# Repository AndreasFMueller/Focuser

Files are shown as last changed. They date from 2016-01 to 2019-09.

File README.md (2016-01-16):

# Focuser

The motor focus driver from starizona is quite feature complete,
more so than many other devices, but it is very large and heavy.
Also it is not possible to actuate the focuser without grabbing
the device, a wireless solution would be preferable. The present
project solves this problem.

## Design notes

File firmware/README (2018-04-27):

README for the focuser firmware project
---------------------------------------

Since the firmware reads the serial number from eeprom, it is necessary
to write the eeprom after flashing the device. The "make flash" command
is supposed to do that. But the serial number will then be 0000000. Use
the "serial" command of the fclient programm to set the serial number.

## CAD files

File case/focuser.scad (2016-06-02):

/*
 * focuser.stl -- case for the focuser 
 *
 * (c) 2016 Prof Dr Andreas Mueller, Hochschule Rapperswil
 */

board_width = 60.96 + 2 * 0.2;
board_height = 41.28 + 2 * 0.2;

w = board_width + 2 * 8;
h = board_height;
thickness = 1.5;
d = 10;

wall = 2;
W = w + 2 * wall;
H = h + 2 * wall;
D = d + 2 * wall;

dl = wall + 2 + thickness;
du = wall + d + 2;

module screwhole() {
    cylinder(r = 1.2, h = 20, center = true);
}

module bottom() {
	difference() {
		translate([0, 0, dl/2]) cube([W, H, dl], center = true);
		union() {
			translate([0, 0, wall + 2 + 1.5])
				cube([board_width, board_height, 3], center = true);
            translate([0, 0, wall + 5])
				cube([board_width - 1, board_height - 1, 10], center = true);
            // screw holes
            translate([board_width/2 + 6, 0, 0])
                screwhole();
            translate([-board_width/2 - 6, board_height/2 - 2, 0])
                screwhole();
            translate([-board_width/2 - 6, -board_height/2 + 2, 0])
                screwhole();
//            translate([0, 0, 5 + wall + 2 + 1.5 - 1])
//            difference() {
//                cube([W + 2, H + 2, 10], center = true);
//                cube([W - wall, H - wall, 12], center = true);
//            }
		}
	}
}

module screw() {
    union() {
        cylinder(r = 1.7, h = 30, center = true, $fn = 20);
        translate([0, 0, d-1])
            cylinder(r1 = 0, r2 = 3, h = 3, $fn = 20);
        translate([0, 0, d+2])
            cylinder(r = 3, h = 10, $fn = 20);
    }
}

module top() {
    difference() {
        union() {
            difference() {
                translate([0, 0, du / 2]) cube([W, H, du], center = true);
                union() {
                    translate([-3, 0, d/2 + 1])
                        cube([w - 6, h, d + 2], center = true);
                    // USB connector
                    translate([w / 2, 10.5, 10 - d + 2])
                        cube([20, 14, 20], center = true);
                    // motor cable opening
                    translate([w/2, -10, du/2 -d + 2.5])
                        cube([20, 5, 6], center = true);
                    // motor connector
                    //translate([w / 2, -10, du/2 - d + 2])
                    //    cube([20, 12, du], center = true);
                    // power cable opening
                    translate([w / 2 - 2, 12 + 4, 3.5 - d])
                        cube([10, 10, 20], center = true);
                }
            }
            translate([-board_width/2 - 6, board_height/2 - 2, du/2])
                cube([7, 7, du], center = true);
            translate([-board_width/2 - 6, -board_height/2 + 2, du/2])
                cube([7, 7, du], center = true);
            // board clamps bottom
            translate([0, -board_height/2, du/2])
                cube([4, 2, du], center = true);
            // board clamps top
            translate([board_width / 3, board_height/2, du/2])
                cube([4, 2, du], center = true);
            translate([-board_width / 3, board_height/2, du/2])
                cube([4, 2, du], center = true);
        }
        union() {
            // screw holes
            translate([board_width/2 + 6, 0, 0]) screw();
            translate([-board_width/2 - 6, board_height/2 - 2, 0]) screw();
            translate([-board_width/2 - 6, -board_height/2 + 2, 0]) screw();
            // LED holes
            translate([6, -16, 0])
                cylinder(r = 2.0, h = 30, center = true, $fn = 20);
            translate([27, -2, 0])
                cylinder(r = 2.0, h = 30, center = true, $fn = 20);
            translate([-11.5, 10.5, 0])
                cylinder(r = 2.0, h = 30, center = true, $fn = 20);
        }
    }
}

translate([0, 50, d + 4]) rotate([180, 0, 0]) top();
bottom();

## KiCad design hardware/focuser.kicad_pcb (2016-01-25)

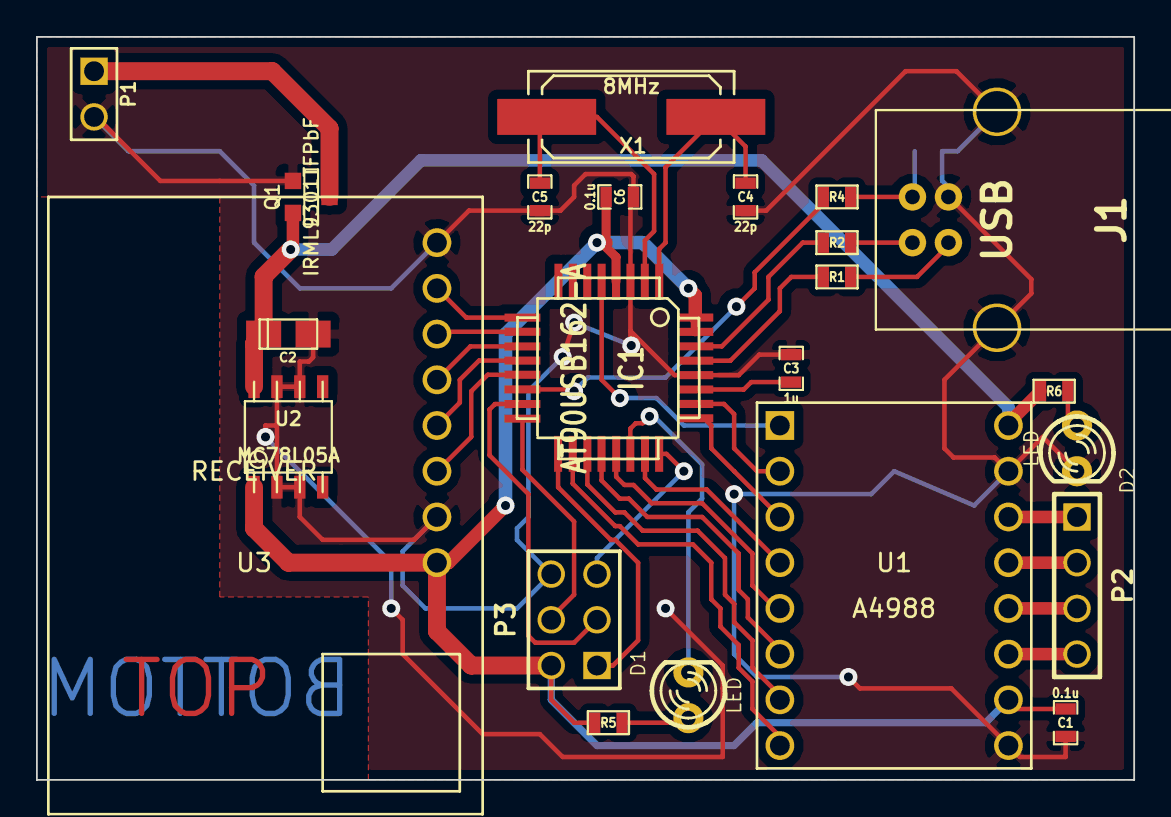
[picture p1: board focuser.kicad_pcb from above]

Board: 2 copper layers, 61.0 x 41.3 mm, 24 parts (1 on the bottom side), 37 nets.

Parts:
C1, C6: 0.1u; SM0603_Capa
C2: 0.33u; c_tant_A
C3: 1u; SM0603_Capa
C4, C5: 22p; SM0603_Capa
D1, D2: LED; LED-3MM
IC1: AT90USB162-A; TQFP32
J1: USB; USB_B
P1: Power; PIN_ARRAY_2X1
P2: Motor; PIN_ARRAY_4x1
P3: ISP; pin_array_3x2
Q1: IRML9301TFPbF; SOT23GDS
R1, R2: 22; SM0603
R3: 220k; SM0603
R4: 1k; SM0603
R5: 610; SM0603
R6: 2k; SM0603
U1: A4988
U2: MC78L05A; so-8
U3: RECEIVER; Receiver
X1: 8MHz; Q_49U3HMS

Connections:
+5V: C1.1, C6.1, IC1.4, IC1.31, IC1.32, P3.2, R5.2, U1.10, U2.1, U3.1
+12V: C2.1, Q1.S, R6.1, U1.16, U2.8
GND: C1.2, C2.2, C3.2, C4.1, C5.1, C6.2, D2.2, IC1.3, IC1.28, J1.4, J1.5, J1.6, P1.2, P3.6, Q1.G, R3.2, U1.9, U1.15, U2.2, U2.3, U2.6, U2.7, U3.2, U3.8
unnamed: C4.2, IC1.1, X1.1
unnamed: C5.2, IC1.2, X1.2
unnamed: IC1.30, R2.2
unnamed: IC1.29, R1.2
unnamed: IC1.16, P3.4
unnamed: IC1.24, P3.5
unnamed: IC1.15, P3.3
unnamed: IC1.17, P3.1
unnamed: D1.2, IC1.22
unnamed: D2.1, R6.2
unnamed: D1.1, R5.1
unnamed: P2.4, U1.11
unnamed: P2.3, U1.12
unnamed: P2.2, U1.13
unnamed: P2.1, U1.14
unnamed: P1.1, Q1.D
unnamed: IC1.13, U3.3
unnamed: IC1.12, U3.4
unnamed: IC1.11, U3.5
unnamed: IC1.10, U3.6
unnamed: IC1.9, U3.7
unnamed: IC1.25, U1.3
unnamed: IC1.26, U1.2
unnamed: IC1.23, U1.4
unnamed: IC1.5, U1.1
unnamed: C3.1, IC1.27
unnamed: IC1.14, R4.1
unnamed: J1.1, R3.1, R4.2
unnamed: IC1.18, U1.8
unnamed: IC1.19, U1.7
unnamed: IC1.20, U1.6
unnamed: IC1.21, U1.5
unnamed: J1.3, R1.1
unnamed: J1.2, R2.1

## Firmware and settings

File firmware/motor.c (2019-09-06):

/*
 * motor.c -- implementation of motor control functions
 *
 * (c) 2016 Prof Dr Andreas Mueller, HOchschule Rapperswil
 */
#include <motor.h>
#include <avr/io.h>
#include <LUFA/Platform/Platform.h>
#include <LUFA/Drivers/USB/USB.h>
#include <avr/eeprom.h>
#include <led.h>
#include <eeprom.h>

#define	MOTOR_ENABLE	PORTC2
#define MOTOR_MS1	PORTC4
#define MOTOR_MS2	PORTC5
#define MOTOR_MS3	PORTC6
#define MOTOR_RESET	PORTB7
#define	MOTOR_SLEEP	PORTB6
#define MOTOR_STEP	PORTB5
#define MOTOR_DIR	PORTB4

#define	MS_MASK		(_BV(PORTC4)|_BV(PORTC5)|_BV(PORTC6))

volatile unsigned char	saveneeded = 0;

/**
 * \brief Set the motor stepping mode
 */
void	motor_set_step(unsigned char step) {
	unsigned char	c = PORTC;
	c = (c & ~MS_MASK) | ((step << 4) & MS_MASK);
	PORTC = c;
}

/**
 * \brief Get the motor stepping mode
 */
unsigned char	motor_get_step() {
	return (PORTC & MS_MASK) >> 4;
}

static volatile uint32_t	current;
static volatile uint32_t	target;
static unsigned char	speed = SPEED_SLOW;
static unsigned char	divisor;
static unsigned char	microstep;
static unsigned char	stepsize;

/**
 * \brief Get the current motor position
 */
uint32_t	motor_current() {
	return current;
}

uint32_t	motor_speed() {
	return speed;
}

volatile uint32_t	lastsaved;
static volatile uint32_t	timelastchanged = 0;

/**
 * \brief Get the current target setting
 *
 * Get the current target value. The host software can detect whether
 * the motor is moving by checking whether the target and the current
 * position are different.
 */
uint32_t	motor_target() {
	return target;
}

#define	DIVISOR	2

/**
 * \brief save the current value
 */
void	motor_save() {
	GlobalInterruptDisable();
	eeprom_write_dword(&position, lastsaved);
	saveneeded = 0;
	GlobalInterruptEnable();
}

/**
 * \brief Handler called from the timer interrupt
 *
 * This function is called from the timer interrupt. If the current position
 * differs from the target, an impuls to the stepper motor driver is generated.
 * The current position in the variable current is then incremented.
 */
void	motor_handler() {
	if (current == target) {
		if (timelastchanged < 0xffffffff) {
			timelastchanged++;
		}
		if (timelastchanged == 120000) {
			if (lastsaved != current) {
				lastsaved = current;
				saveneeded = 1;
			}
		}
		return;
	}
	timelastchanged = 0;
	// set the direction
	if (0 == --divisor) {
		if (speed == SPEED_SLOW) {
			if (target > current) {
				microstep = (microstep + 1) % 16;
				if (0 == microstep) {
					PORTB |= _BV(MOTOR_DIR);
					current++;
				}
			} else {
				microstep = (microstep + 15) % 16;
				if (0 == microstep) {
					PORTB &= ~_BV(MOTOR_DIR);
					current--;
				}
			}
		} else {
			if (target > current) {
				microstep = (microstep + stepsize) % 16;
				if (0 == microstep) {
					PORTB |= _BV(MOTOR_DIR);
					current++;
				}
			} else {
				microstep = (microstep + (16 - stepsize)) % 16;
				if (0 == microstep) {
					PORTB &= ~_BV(MOTOR_DIR);
					current--;
				}
			}
		}
		// send a pulse
		PORTB |= _BV(MOTOR_STEP);
		PORTB &= ~_BV(MOTOR_STEP);
		// set the speed divisor to the appropriate value
		divisor = DIVISOR;
	}
}

void	motor_moveto(uint32_t position, unsigned char _speed) {
	GlobalInterruptDisable();
	target = position;
#if 0
	// if switching to slow speed, reset microstep counter
	if ((speed != _speed) && (_speed == SPEED_SLOW)) {
		microstep = 0;
	}
#else
	// always reset the microstep counter
	microstep = 0;
#endif
	speed = _speed;
	switch (speed) {
	case SPEED_FAST: {
			unsigned char	s = motor_faststep();
			motor_set_step(s);
			switch (s) {
				case 0:	stepsize = 16; break;
				case 1:	stepsize =  8; break;
				case 2:	stepsize =  4; break;
				case 3:	stepsize =  2; break;
			}
		}
		break;
	case SPEED_SLOW:
		motor_set_step(STEP_SIXTEENTH);
		break;
	}
	GlobalInterruptEnable();
}

void	motor_position(uint32_t position) {
	GlobalInterruptDisable();
	target = position;
	current = position;
	GlobalInterruptEnable();
}

/**
 * \brief Stop the motor
 *
 * The motor is stopped by setting the target value to the current value,
 * which implies that there is no need to step any further.
 */
void	motor_stop() {
	GlobalInterruptDisable();
	if (current != target) {
		target = current;
	}
	GlobalInterruptEnable();
}

void	motor_setup(void) __attribute__ ((constructor));
/**
 * \brief Setup for the motor driver
 *
 * This constructor should be called during initialization to properly
 * initialize the outputs to the Pololu stepper driver.
 */
void	motor_setup(void) {
	motor_set_step(STEP_SIXTEENTH);
	PORTC &= ~_BV(MOTOR_ENABLE);
	PORTB |= _BV(MOTOR_SLEEP);
	PORTB &= ~_BV(MOTOR_STEP);
	PORTB &= ~_BV(MOTOR_DIR);
	PORTB |= _BV(MOTOR_RESET);
	DDRC |= 0x74;
	DDRB |= 0xf0;
	// read the current value from the EEPROM
	current = eeprom_read_dword(&position);
	lastsaved = current;
	// set the target also to the current, so we don't move anything
	target = current;
	microstep = 0;
}

static uint8_t	lasttopspeed = 0xff;

/**
 * \brief Get the top speed byte (0 for fastest, 4 for slowest)
 *
 * \return	the top speed byte
 */
uint8_t	motor_get_topspeed() {
	if (lasttopspeed == 0xff) {
		lasttopspeed = eeprom_read_byte(&topspeed);
		if (lasttopspeed > 3) {
			lasttopspeed = 0;
			eeprom_write_byte(&topspeed, lasttopspeed);
		}
	}
	return lasttopspeed;
}

/**
 * \brief Set the top speed in the EEPROM
 *
 * \param settopspeed	the top speed value to remember
 */
void	motor_set_topspeed(uint8_t settopspeed) {
	if (settopspeed > 3) {
		return;
	}
	eeprom_write_byte(&topspeed, settopspeed);
	lasttopspeed = settopspeed;
}

/**
 * \brief Get the step configuration byte from the 
 *
 * \return	get the step configuration byte for the stepper driver
 */
uint8_t	motor_faststep() {
	switch (motor_get_topspeed()) {
	case 0:	return STEP_FULL;
	case 1:	return STEP_HALF;
	case 2:	return STEP_QUARTER;
	case 3: return STEP_EIGHTH;
	}
	/* by default, give the fastest speed (for compatibility) 	*/
	return STEP_FULL;
}

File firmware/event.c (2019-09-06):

/*
 * event.c -- enable event handling
 *
 * (c) 2015 Prof Dr Andreas Mueller, Hochschule Rapperswil
 */
#ifdef HAVE_CONFIG_H
#include <config.h>
#endif /* HAVE_CONFIG_H */
#include <event.h>
#include <receiver.h>
#include <LUFA/Drivers/USB/Core/Events.h>
#include <avr/wdt.h>
#include <motor.h>
#include <timer.h>
#include <serial.h>

/**
 * \brief RESET request
 *
 * The RESET request is handled by simply setting the whatdog timer to
 * such a short interval that it is bound to be triggered.
 */
void	process_reset() {
	Endpoint_ClearSETUP();
	Endpoint_ClearStatusStage();
	// the usual method to set the watchdog timer timeout to
	// a short time does not really work, because interrupts happen
	// so often in this application. We use the reset flag from
	// the timer, which tells the timer interrupt no longer to reset
	// the watchdog timer, which will utlimately cause a watch dog timer
	// reset
	resetflag = 0;
}

/**
 * \brief SET request
 *
 * The SET request moves the focuser to a position indicated by the wValue
 * field in the request. If wIndex is nonzero, then the movement is done
 * in high speed mode, otherwise in slow speed.
 */
void	process_set() {
	uint32_t	position = 0;
	Endpoint_ClearSETUP();
	Endpoint_Read_Control_Stream_LE((void *)&position, sizeof(position));
	Endpoint_ClearIN();
	// ignore set commands that go beyond the accpetable range
	if (position > 0xffffff) {
		return;
	}
	// treat end points of range differently
	if ((position == 0) || (position == 0xffffff)) {
		return;
	}
	motor_moveto(position,
		(USB_ControlRequest.wIndex) ? SPEED_FAST : SPEED_SLOW);
}

/**
 * \brief LOCK request
 *
 * The LOCK request disables focus changes 
 */
void	process_lock() {
	Endpoint_ClearSETUP();
	Endpoint_ClearStatusStage();
	if (USB_ControlRequest.wIndex) {
		recv_lock();
	} else {
		recv_unlock();
	}
}

/**
 * \brief STOP request
 *
 * The stop request works by setting the target to the current counter state
 */
void	process_stop() {
	Endpoint_ClearSETUP();
	Endpoint_ClearStatusStage();
	motor_stop();
}

/**
 * \brief SERIAL request
 *
 * read the new serial number in ascii from the USB and copy it into the
 * 
 */
void	process_serial() {
	Endpoint_ClearSETUP();
	unsigned char	l = USB_ControlRequest.wLength;
	if (l <= 7) {
		Endpoint_Read_Control_Stream_LE(serialbuffer, l);
	}
	Endpoint_ClearIN();
	serialbuffer[l] = '\0';
	newserial = 1;
}

/**
 * \brief POSITION request
 *
 * sets the position to a specific value
 */
void	process_position() {
	Endpoint_ClearSETUP();
	uint32_t	zeroposition = 0x800000;
	Endpoint_Read_Control_Stream_LE((void *)&zeroposition,
		sizeof(zeroposition));
	Endpoint_ClearIN();
	if (zeroposition > 0xfffffe) {
		return;
	}
	motor_position(zeroposition);
	motor_save();
}

/**
 * \brief set TOPSPEED request
 */
void	process_set_topspeed() {
	Endpoint_ClearSETUP();
	uint8_t	settopspeed = 0x00;
	Endpoint_Read_Control_Stream_LE((void *)&settopspeed,
		sizeof(settopspeed));
	Endpoint_ClearIN();
	motor_set_topspeed(settopspeed);
}

#define	is_control() \
	((USB_ControlRequest.bmRequestType & CONTROL_REQTYPE_TYPE) 	\
		== REQTYPE_VENDOR) 					\
	&&								\
	((USB_ControlRequest.bmRequestType & CONTROL_REQTYPE_RECIPIENT)\
		== REQREC_DEVICE)

#define	is_incoming() \
	((USB_ControlRequest.bmRequestType & CONTROL_REQTYPE_DIRECTION)	\
		== REQDIR_HOSTTODEVICE)

#define	is_outgoing() \
	((USB_ControlRequest.bmRequestType & CONTROL_REQTYPE_DIRECTION)	\
		== REQDIR_DEVICETOHOST)

/**
 * \brief Get the current focuser state
 *
 * The GET request returns a single byte containing the state of all
 * the output ports.
 */
void	process_get() {
	Endpoint_ClearSETUP();
	int32_t	v[3];
	v[0] = motor_current();
	v[1] = motor_target();
	v[2] = motor_speed();
	Endpoint_Write_Control_Stream_LE((void *)v, sizeof(v));
	Endpoint_ClearOUT();
}

/**
 * \brief RCVR request implementation
 *
 * retrieve the current state of the input pins from the RF receiver
 */
void	process_rcvr() {
	Endpoint_ClearSETUP();
	unsigned char	v = recv_get();
	Endpoint_Write_Control_Stream_LE((void *)&v, 1);
	Endpoint_ClearOUT();
}

/**
 * \brief SAVED request implementation
 */
void	process_saved() {
	Endpoint_ClearSETUP();
	uint32_t	v = lastsaved;
	Endpoint_Write_Control_Stream_LE((void *)&v, sizeof(v));
	Endpoint_ClearOUT();
}

/**
 * \brief set TOPSPEED implementation
 */
void	process_get_topspeed() {
	Endpoint_ClearSETUP();
	unsigned char	v = motor_get_topspeed();
	Endpoint_Write_Control_Stream_LE((void *)&v, 1);
	Endpoint_ClearOUT();
}

/**
 * \brief Control request event handler
 *
 * This implementation handles the control requests for the GuiderPort device
 */
void	EVENT_USB_Device_ControlRequest() {
	if (is_control()) {
		if (is_incoming()) {
			switch (USB_ControlRequest.bRequest) {
			case FOCUSER_RESET:
				process_reset();
				break;
			case FOCUSER_SET:
				process_set();
				break;
			case FOCUSER_LOCK:
				process_lock();
				break;
			case FOCUSER_STOP:
				process_stop();
				break;
			case FOCUSER_SERIAL:
				process_serial();
				break;
			case FOCUSER_POSITION:
				process_position();
				break;
			case FOCUSER_TOPSPEED:
				process_set_topspeed();
				break;
			}
		}
		if (is_outgoing()) {
			switch (USB_ControlRequest.bRequest) {
			case FOCUSER_GET:
				process_get();
				break;
			case FOCUSER_RCVR:
				process_rcvr();
				break;
			case FOCUSER_SAVED:
				process_saved();
				break;
			case FOCUSER_TOPSPEED:
				process_get_topspeed();
				break;
			}
		}
	}
}

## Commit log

2016-01-16 add focuser schematics and layout
    [focuser.kicad_pcb, focuser.sch]
2016-01-25 make manufacturable boards (according to Eurocircuit's rules)
    [focuser.kicad_pcb]
2016-02-10 remove led_on from motor_save
2016-05-17 fix some minor bugs
    [motor.c, receiver.c]
2016-05-31 fix position counter for microstepping
    [motor.c]
2016-06-02 add focuser case to repo
    [focuser.scad]
